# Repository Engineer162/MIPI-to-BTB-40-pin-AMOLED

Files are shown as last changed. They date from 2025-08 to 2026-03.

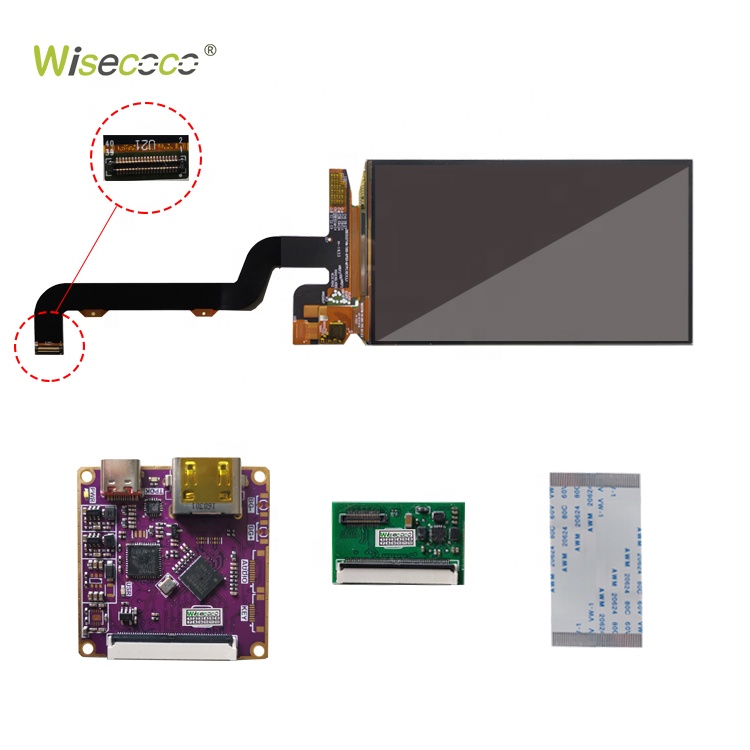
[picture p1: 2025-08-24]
TOP055FHDTOOCTP01/Pictures/Hfb517dd607b943e793b4186fe94c6ae0u.jpg

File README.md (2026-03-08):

# MIPI-to-BTB-40-pin-AMOLED

This PCB takes a 4 lane MIPI DSI input from for example a raspberry pi 5 and makes it compatible with a 40 pin 5806 Board to Board connector used on the TOP055FHDTOOCTP01 AMOLED display

# Warning:

Please make sure that the display that you use has a connector that is pin to pin compatible with this design. If it isnt, then feel free to change it to your display using its provided datasheet.

# Status:

6/3/2026: Hardware has been finalised for testing.

8/3/2026: Driver and .dtsi file has been written for Linux, and will be tested when HAT hardware has been assembled

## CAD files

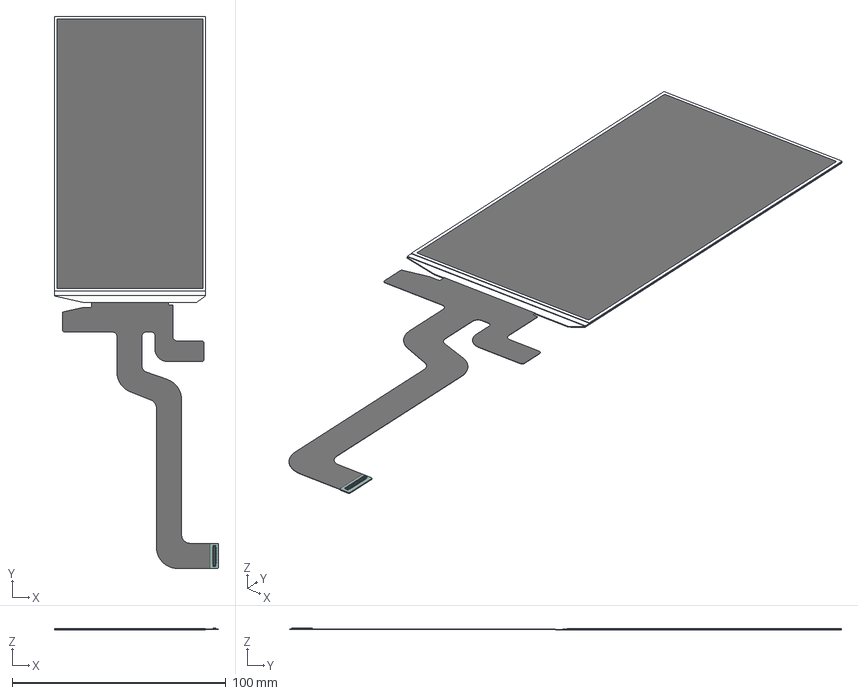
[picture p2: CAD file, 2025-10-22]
TOP055FHDTOOCTP01/3D model/TOP055FHDTOOCTP01 flat.step
76.8 x 258.2 x 0.9 mm
Plug_W_AP_Rev0_AllCATPart
FPCB
Display glass

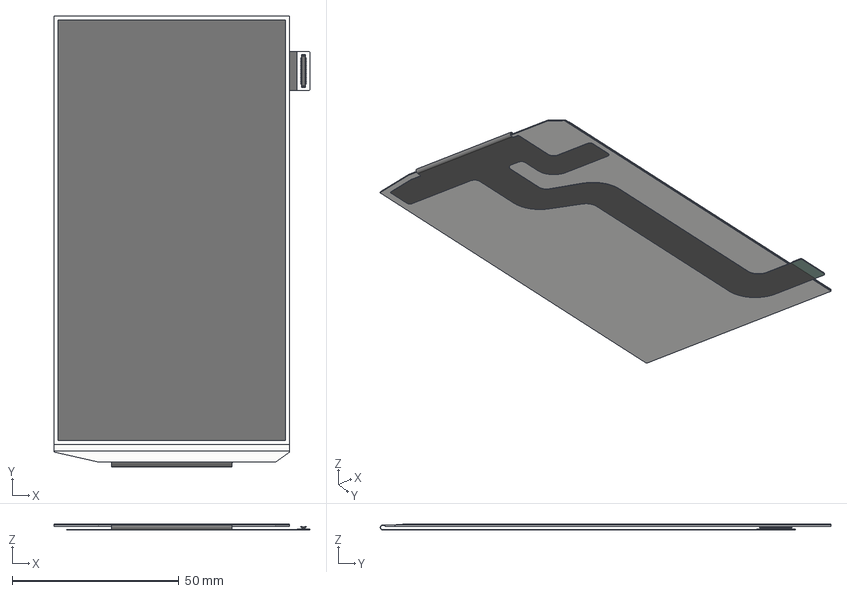
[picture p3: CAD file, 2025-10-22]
TOP055FHDTOOCTP01/3D model/TOP055FHDTOOCTP01 folded.step
76.8 x 135.2 x 1.81 mm
Plug_W_AP_Rev0_AllCATPart
FPCB
Display glass

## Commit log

2025-08-24 Uploaded Datasheets, Schematics, and a picture
2025-08-26 Added a HW sequencer for the display power up
2025-08-27 Finished the Debug schematic
    All connections and power logic has been implemented.
2025-09-22 Added final schematic and PCB file for production testing
2025-09-23 Fixed diode D1 being accidentally reversed
2025-10-05 Fixed a bunch of stuff related to the PCB
    Troubleshooting results:
    1) The stencil was too thin, not allowing proper contact between the PCB and the TI boost converter. Causing the negative rail enable pin to not make contact and never turn on (this is why the screen was yellow)
    2) The coils produced coil whine, however this was likely due to the negative rail not working, so i will hold off on fixing that for now.
    3) The RP5 3.3V rail on the MIPI connector is only on when the pi is on, this means that i can use it as a power on signal for the display, and not rely on an external GPIO input.
    4) The schematic features two 3.3V nets by mistake, one labeled 3.3V and the main net being labeled +3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
2025-10-05 Updated a bunch of stuff in the schematic and PCB
    4) The schematic features two 3.3V nets by mistake, one labeled 3.3V and the main net being la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
2025-10-05 Added jumpers
    Added jumpers to choose between a hardware sequencer panel power on or a gpio panel power on method.
2025-10-05 Fixed PCB file having weird text in the middle of the PCB
2025-10-13 Changed the layer count from 2 to 4, and fixed the negative rail behaving weirdly
    Changed the layer count from 2 to 4 to add a VIN and GND plane, and fixed the negative rail behaving weirdly by changing the VIN of the TPS65131 to the output of a 4.2V Buck-Boost converter. Changed the voltage source for VLIN1 from VIN to a dedicated 7.5V Buck-Boost converter.
2025-10-21 Recreated the power on sequence timing guideline in Inkscape
    Recreated the power on sequence timing guideline in Inkscape as the one in the display's datasheet was of extremely poor quality.
2025-10-21 Changed the function of the power sequencing
    Changed the function of the power sequencing, so that now the RESET and EL_ON2 pins on the display are controlled by GPIO on the PI5 or CM5 using a driver. The hw sequencer has also been exchanged for one that has more tighter timings.
2025-10-21 Fixed stray ground connection
2025-10-22 Added a 3D model of the display as well as did some restructuring
    Added a 3D model of the TOP055FHDTOOCTP01 AMOLED display as well as did some directory restructuring.
    [TOP055FHDTOOCTP01.step]
2025-10-22 Added a "folded" 3D model of the display
    [TOP055FHDTOOCTP01 flat.step, TOP055FHDTOOCTP01 folded.step, TOP055FHDTOOCTP01.step]
2026-02-12 Started work on a separate board as a Raspberry Pi 5 HAT to make handling easier
2026-03-05 assigned all pins in schematic
2026-03-06 Fixed middle power planes that needed rebuilding
2026-03-08 driver has been written and is ready for testing.
2026-03-09 rename .dtsi and add proper contact info in driver.
